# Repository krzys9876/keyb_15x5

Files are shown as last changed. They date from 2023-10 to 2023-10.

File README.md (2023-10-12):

# Diy mechanical keyboard

This is a dump of all the files that I used to build my custom mech keyboard.

## Layout

To prepare the base layout I used [keyboard-layout-editor](http://www.keyboard-layout-editor.com/). 

I ended-up with [15x5 layout with split space](https://gist.github.com/krzys9876/6718b1eb58f1728975fdd1076bed487b). 
This was my key requirement since what I really wanted was a keyboard with mouse functions built-in. Now, using arrows as mouse movements and split keyboard as left-mid-right mouse buttons I do not need mouse at all. 
Well, maybe this is not the most usefull and ergonomic way to handle mouse but hey, this is all for fun, right?

I tweaked the layout several times since than. The only constraint is the location of the 4 2u keys: space(s) and Enter.

keyb_15x5

## PCB

I created a PCB and schematic sketch using excellent [klepcbgen tool](https://github.com/jeroen94704/klepcbgen). This was a good starting point to tweak the design to match my ideas. 
I had some experience in designing PCBs and electonic circuits in general (see my [ZX Spectrum Diy project](https://github.com/krzys9876/ZX_Spectrum_diy) so it was quite easy. 

But all in all it was not that great - I totally failed with LEDs since I did not use proper footprint for WS2812B-2020 leds. So after I got the boards from JLCPBC it turned out that I cannot use LEDs at all. 
What you see now is a revised version that I did not (yet) put into production.

Other than that the board worked perfectly.

## Firmware

This is a fun project so I would not use any ready-to-use firmware. Anyway I don't think that any of available firmwares would allow me to use mouse. 
So I wrote my own simple version of keyboard handler using Arduino Micro templates and examples. The firmware uses [HID-project](https://github.com/NicoHood/HID).

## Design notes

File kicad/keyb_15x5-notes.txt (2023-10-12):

1. wydłużyć pady przy porcie USB
2. powiększyć pady dla LED
3. wydłużyć pady dla Atmega32u4
4. dodać silkscreen
5. pokazać orientację LED, diod i IC
6. opisać piny ICSP i AUX

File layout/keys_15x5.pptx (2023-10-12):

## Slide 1

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
Bksp

Caps

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
Enter

\

Home

End

Ins

Shift

Fn

Ctrl

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
Ctrl

Shift

PgUp

PgDn

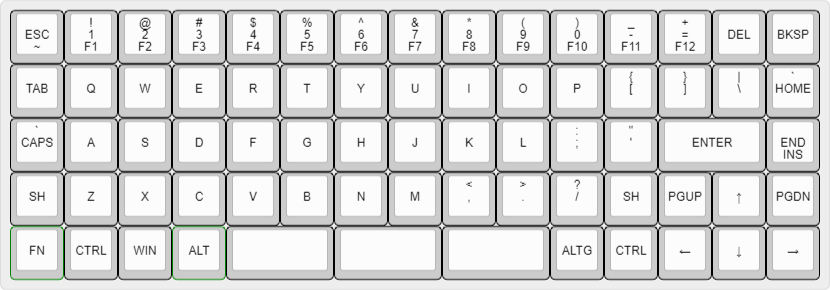
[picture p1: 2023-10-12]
layout/keyb_15x5.png

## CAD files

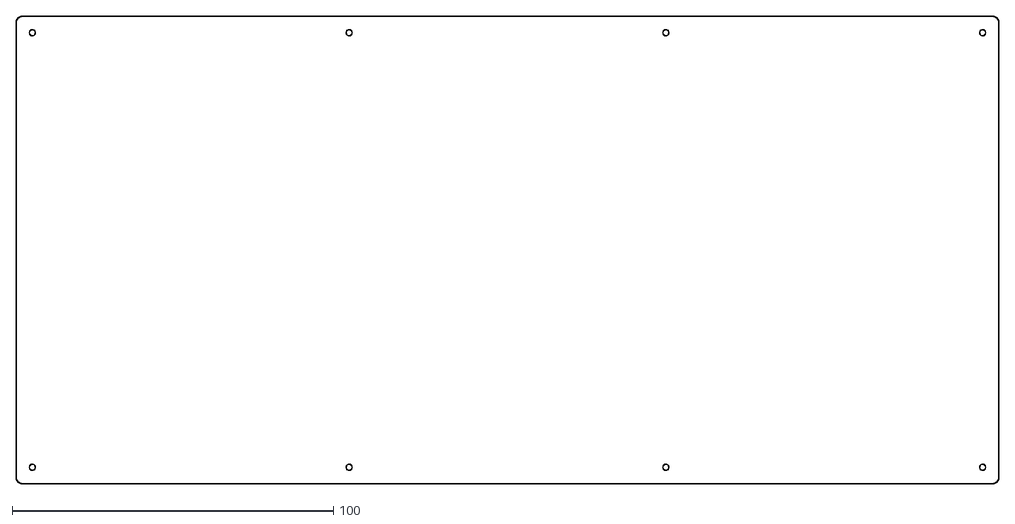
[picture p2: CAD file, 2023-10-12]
layout/e2b42e869952bdb01288ea0626760960afac74d6_bottom.dxf
305.9 x 145.4

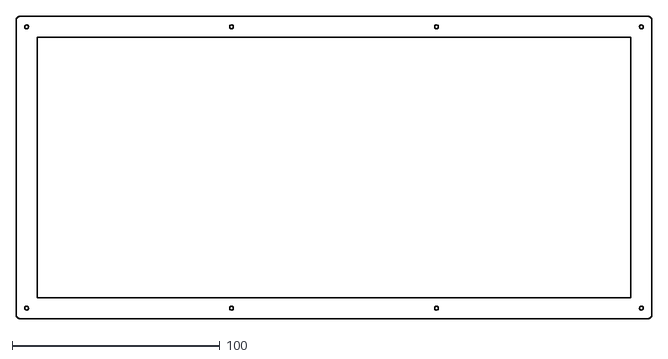
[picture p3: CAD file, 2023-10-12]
layout/e2b42e869952bdb01288ea0626760960afac74d6_closed.dxf
305.9 x 145.4

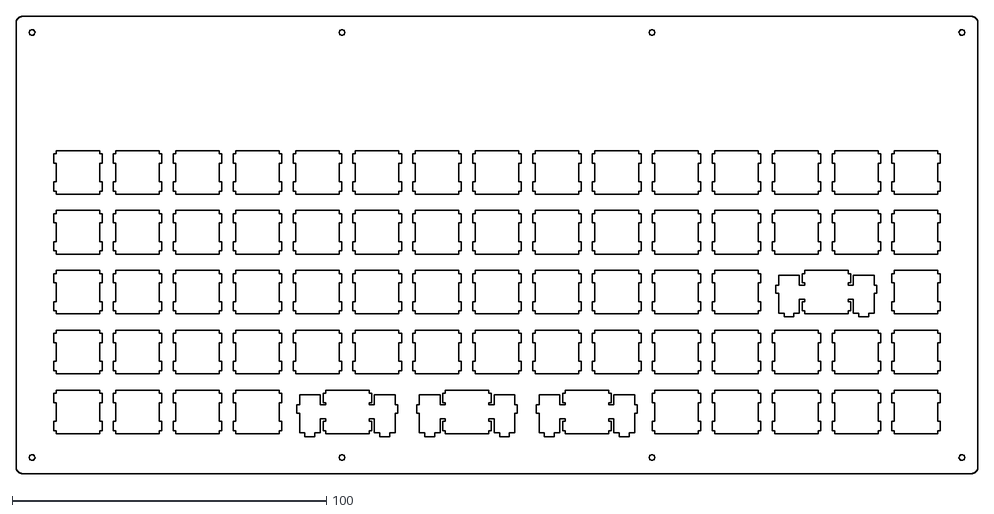
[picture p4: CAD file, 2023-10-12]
layout/e2b42e869952bdb01288ea0626760960afac74d6_switch.dxf
305.9 x 145.4

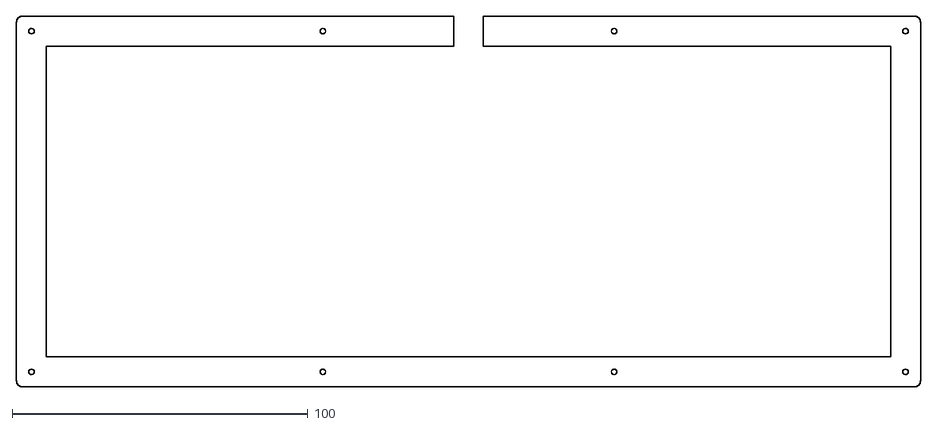
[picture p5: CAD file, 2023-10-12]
layout/71a48d4e9e6aa89030e797956ad6ba44319560fd_open.dxf
305.9 x 125.4

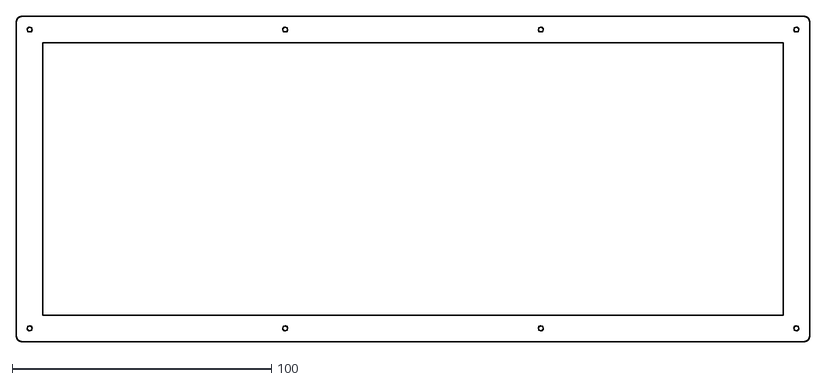
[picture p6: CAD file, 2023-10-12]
layout/71a48d4e9e6aa89030e797956ad6ba44319560fd_closed.dxf
305.9 x 125.4

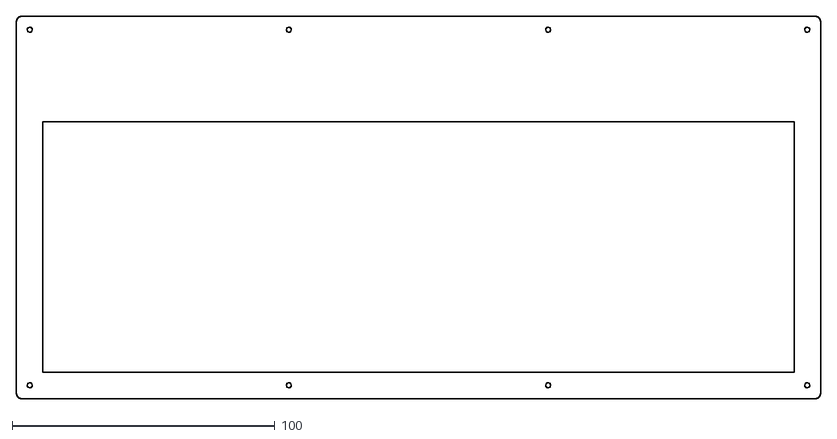
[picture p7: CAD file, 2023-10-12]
layout/e2b42e869952bdb01288ea0626760960afac74d6_top.dxf
305.9 x 145.4

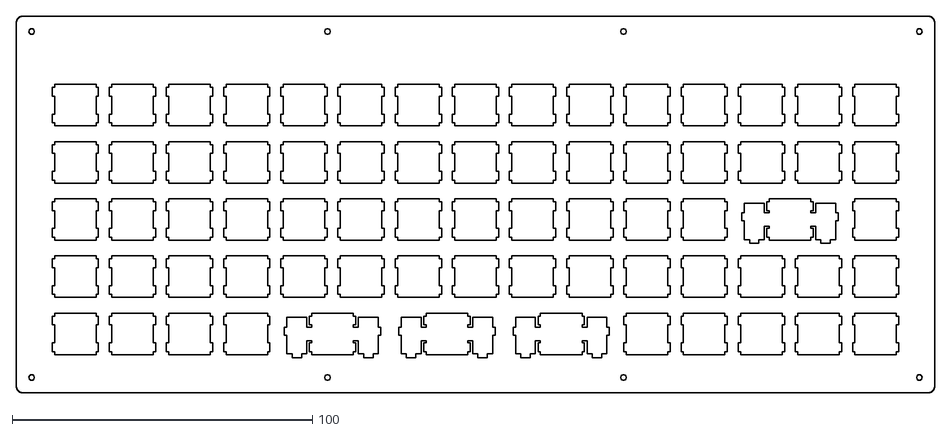
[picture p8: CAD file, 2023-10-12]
layout/71a48d4e9e6aa89030e797956ad6ba44319560fd_switch.dxf
305.9 x 125.4

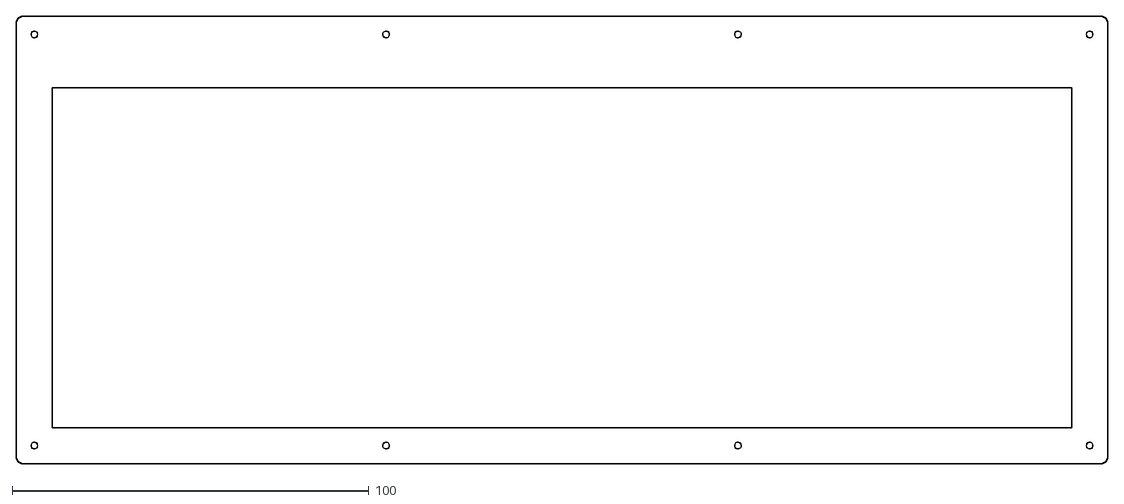
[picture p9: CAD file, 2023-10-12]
layout/71a48d4e9e6aa89030e797956ad6ba44319560fd_top.dxf
305.9 x 125.4

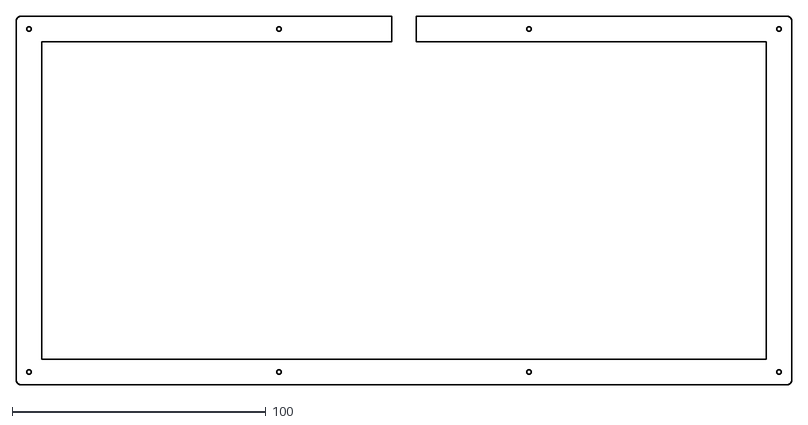
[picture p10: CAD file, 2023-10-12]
layout/e2b42e869952bdb01288ea0626760960afac74d6_open.dxf
305.9 x 145.4

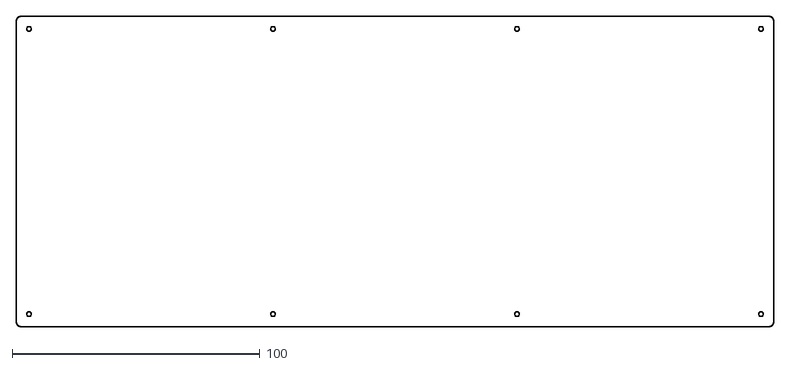
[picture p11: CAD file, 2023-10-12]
layout/71a48d4e9e6aa89030e797956ad6ba44319560fd_bottom.dxf
305.9 x 125.4

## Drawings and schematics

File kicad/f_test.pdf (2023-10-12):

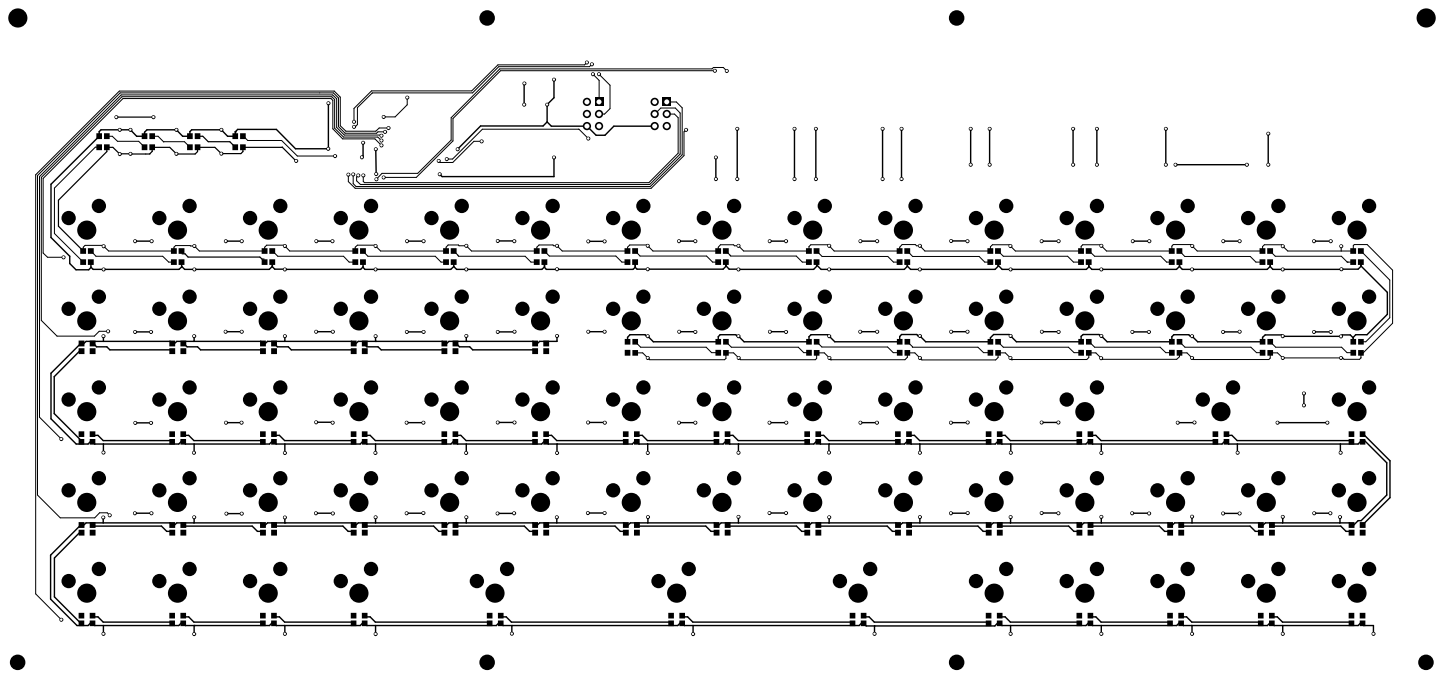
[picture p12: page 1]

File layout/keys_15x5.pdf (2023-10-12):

Esc | ! 1 F1 | @ 2 F2 | # F3 3 | $ F4 4 | % F5 5 | ^ F6 6 | & F7 7 | * F8 8 | ( F9 9 | ) F10 0 | _ F11 - | + F12 = | Del | Bksp
~` Tab | Q | W | E | R | T | Y | U | I | O | P | { [ | } ] | | \ | Home

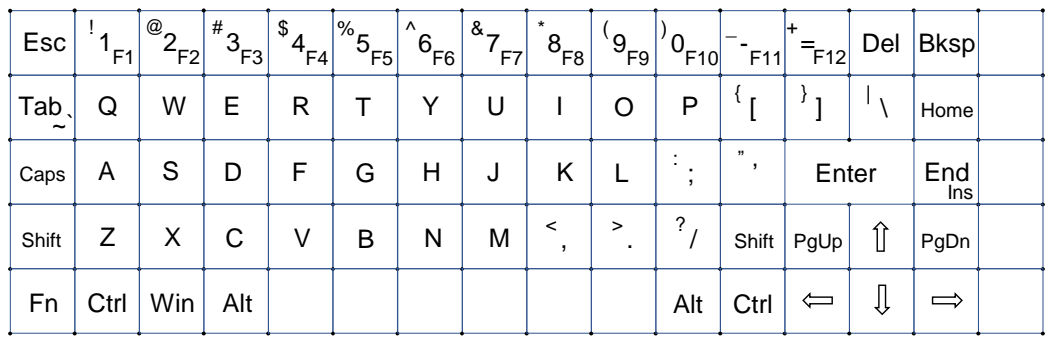
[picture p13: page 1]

Caps | A | S | D | F | G | H | J | K | L | : ; | ” ’ | Enter | | End Ins

Shift | Z | X | C | V | B | N | M | < , | > . | ? / | Shift | PgUp | | PgDn

Fn | Ctrl | Win | Alt | | | | | | | Alt | Ctrl

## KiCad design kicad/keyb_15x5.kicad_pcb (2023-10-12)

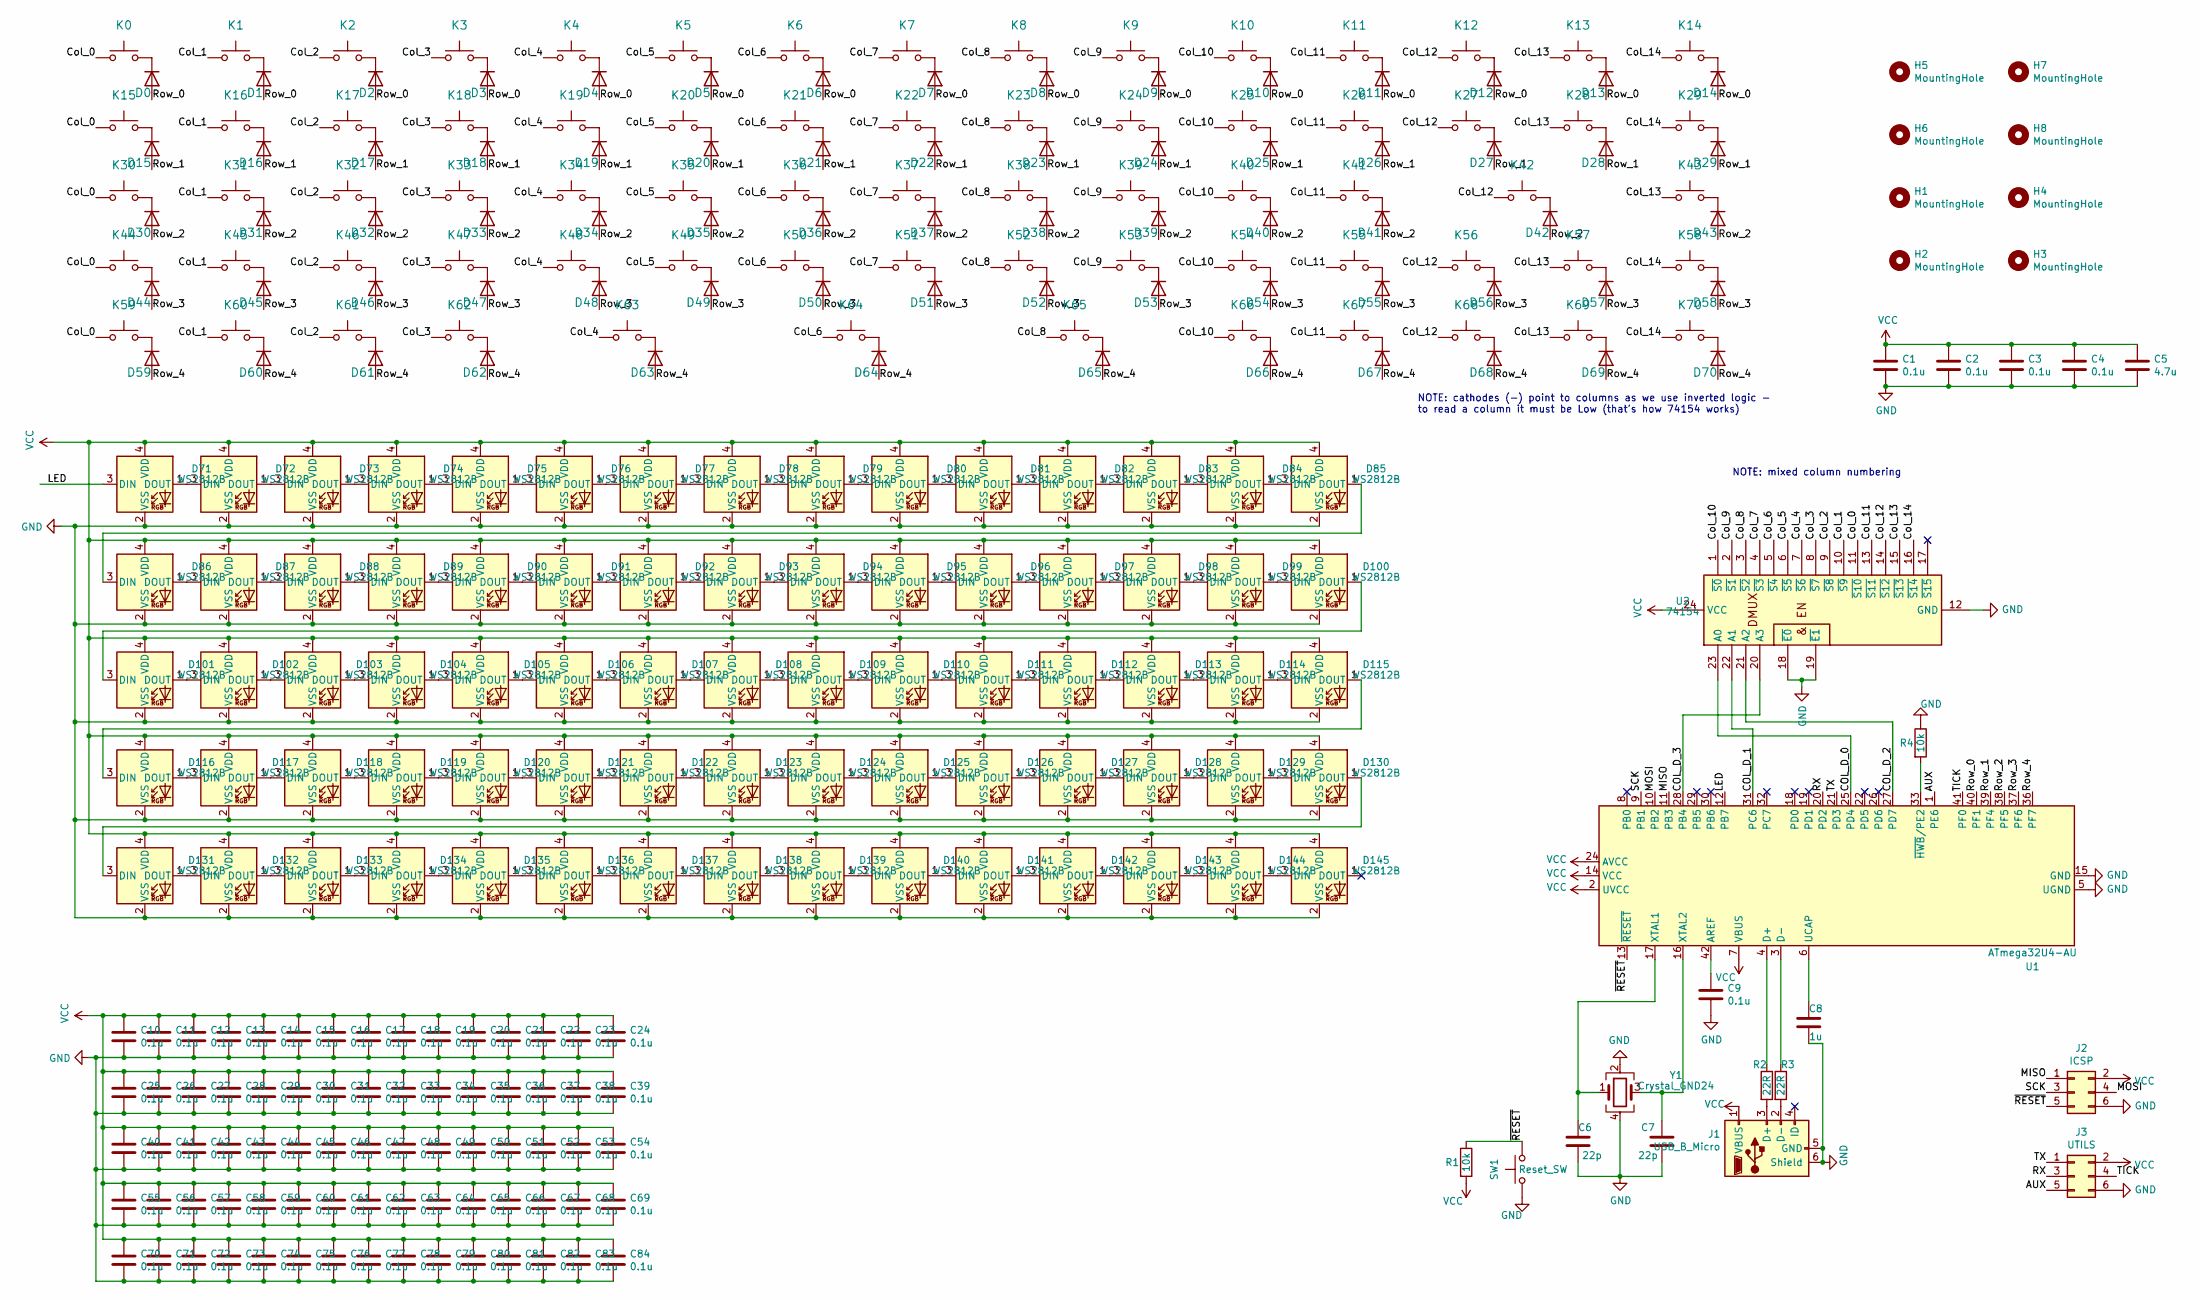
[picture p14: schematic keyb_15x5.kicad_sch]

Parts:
C1, C2, C3, C4, C9, C10, C11, C12, C13, C14, C15, C16, C17, C18, C19, C20, C21, C22, C23, C24, C25, C26, C27, C28, C29, C30, C31, C32, C33, C34, C35, C36, C37, C38, C39, C40, C41, C42, C43, C44, C45, C46, C47, C48, C49, C50, C51, C52, C53, C54, C55, C56, C57, C58, C59, C60, C61, C62, C63, C64, C65, C66, C67, C68, C69, C70, C71, C72, C73, C74, C75, C76, C77, C78, C79, C80, C81, C82, C83, C84: 0.1u; C_0805_2012Metric
C5: 4.7u; C_0805_2012Metric
C6, C7: 22p; C_0805_2012Metric
C8: 1u; C_0805_2012Metric
D0, D1, D2, D3, D4, D5, D6, D7, D8, D9, D10, D11, D12, D13, D14, D15, D16, D17, D18, D19, D20, D21, D22, D23, D24, D25, D26, D27, D28, D29, D30, D31, D32, D33, D34, D35, D36, D37, D38, D39, D40, D41, D42, D43, D44, D45, D46, D47, D48, D49, D50, D51, D52, D53, D54, D55, D56, D57, D58, D59, D60, D61, D62, D63, D64, D65, D66, D67, D68, D69, D70: D; D_0805_2012Metric_Pad1.15x1.40mm_HandSolder
D71, D72, D73, D74, D75, D76, D77, D78, D79, D80, D81, D82, D83, D84, D85, D86, D87, D88, D89, D90, D91, D92, D93, D94, D95, D96, D97, D98, D99, D100, D101, D102, D103, D104, D105, D106, D107, D108, D109, D110, D111, D112, D113, D114, D115, D116, D117, D118, D119, D120, D121, D122, D123, D124, D125, D126, D127, D128, D129, D130, D131, D132, D133, D134, D135, D136, D137, D138, D139, D140, D141, D142, D143, D144, D145: WS2812B; LED_WS2812B_PLCC4_5.0x5.0mm_P3.2mm
H1, H2, H3, H4, H5, H6, H7, H8: MountingHole; MountingHole_3.2mm_M3_DIN965
J1: USB_B_Micro; USB_Micro-B_Amphenol_10104110_Horizontal
J2: ICSP; PinHeader_2x03_P2.54mm_Vertical
J3: UTILS; PinHeader_2x03_P2.54mm_Vertical
K0, K1, K2, K3, K4, K5, K6, K7, K8, K9, K10, K11, K12, K13, K14, K15, K16, K17, K18, K19, K20, K21, K22, K23, K24, K25, K26, K27, K28, K29, K30, K31, K32, K33, K34, K35, K36, K37, K38, K39, K40, K41, K42, K43, K44, K45, K46, K47, K48, K49, K50, K51, K52, K53, K54, K55, K56, K57, K58, K59, K60, K61, K62, K63, K64, K65, K66, K67, K68, K69, K70: KEYSW; Kailh_socket_MX_platemount
R1, R4: 10k; R_0805_2012Metric_Pad1.15x1.40mm_HandSolder
R2, R3: 22R; R_0805_2012Metric_Pad1.15x1.40mm_HandSolder
SW1: Reset_SW; SW_Push_1P1T_NO_6x6mm_H9.5mm
U1: ATmega32U4-AU; TQFP-44_10x10mm_P0.8mm
U2: 74154; SOIC-24W_7.5x15.4mm_P1.27mm
Y1: Crystal_GND24; Crystal_SMD_3225-4Pin_3.2x2.5mm_HandSoldering

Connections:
/AUX: J3.5, U1.1 (PE6)
/COL_D_0: U1.25 (PD4), U2.23 (A0)
/COL_D_1: U1.31 (PC6), U2.22 (A1)
/COL_D_2: U1.27 (PD7), U2.21 (A2)
/COL_D_3: U1.28 (PB4), U2.20 (A3)
/Col_0: K0.1, K15.1, K30.1, K44.1, K59.1, U2.11 (~S10)
/Col_1: K1.1, K16.1, K31.1, K45.1, K60.1, U2.10 (~S9)
/Col_2: K2.1, K17.1, K32.1, K46.1, K61.1, U2.9 (~S8)
/Col_3: K3.1, K18.1, K33.1, K47.1, K62.1, U2.8 (~S7)
/Col_4: K4.1, K19.1, K34.1, K48.1, K63.1, U2.7 (~S6)
/Col_5: K5.1, K20.1, K35.1, K49.1, U2.6 (~S5)
/Col_6: K6.1, K21.1, K36.1, K50.1, K64.1, U2.5 (~S4)
/Col_7: K7.1, K22.1, K37.1, K51.1, U2.4 (~S3)
/Col_8: K8.1, K23.1, K38.1, K52.1, K65.1, U2.3 (~S2)
/Col_9: K9.1, K24.1, K39.1, K53.1, U2.2 (~S1)
/Col_10: K10.1, K25.1, K40.1, K54.1, K66.1, U2.1 (~S0)
/Col_11: K11.1, K26.1, K41.1, K55.1, K67.1, U2.13 (~S11)
/Col_12: K12.1, K27.1, K42.1, K56.1, K68.1, U2.14 (~S12)
/Col_13: K13.1, K28.1, K43.1, K57.1, K69.1, U2.15 (~S13)
/Col_14: K14.1, K29.1, K58.1, K70.1, U2.16 (~S14)
/LED: D71.3 (DIN), U1.12 (PB7)
/MISO: J2.1, U1.11 (PB3)
/MOSI: J2.4, U1.10 (PB2)
/RX: J3.3, U1.20 (PD2)
/Row_0: D0.2 (A), D1.2 (A), D2.2 (A), D3.2 (A), D4.2 (A), D5.2 (A), D6.2 (A), D7.2 (A), D8.2 (A), D9.2 (A), D10.2 (A), D11.2 (A), D12.2 (A), D13.2 (A), D14.2 (A), U1.40 (PF1)
/Row_1: D15.2 (A), D16.2 (A), D17.2 (A), D18.2 (A), D19.2 (A), D20.2 (A), D21.2 (A), D22.2 (A), D23.2 (A), D24.2 (A), D25.2 (A), D26.2 (A), D27.2 (A), D28.2 (A), D29.2 (A), U1.39 (PF4)
/Row_2: D30.2 (A), D31.2 (A), D32.2 (A), D33.2 (A), D34.2 (A), D35.2 (A), D36.2 (A), D37.2 (A), D38.2 (A), D39.2 (A), D40.2 (A), D41.2 (A), D42.2 (A), D43.2 (A), U1.38 (PF5)
/Row_3: D44.2 (A), D45.2 (A), D46.2 (A), D47.2 (A), D48.2 (A), D49.2 (A), D50.2 (A), D51.2 (A), D52.2 (A), D53.2 (A), D54.2 (A), D55.2 (A), D56.2 (A), D57.2 (A), D58.2 (A), U1.37 (PF6)
/Row_4: D59.2 (A), D60.2 (A), D61.2 (A), D62.2 (A), D63.2 (A), D64.2 (A), D65.2 (A), D66.2 (A), D67.2 (A), D68.2 (A), D69.2 (A), D70.2 (A), U1.36 (PF7)
/SCK: J2.3, U1.9 (PB1)
/TICK: J3.4, U1.41 (PF0)
/TX: J3.1, U1.21 (PD3)
/~RESET: J2.5, R1.1, SW1.2, U1.13 (~RESET)
GND: C1.2, C2.2, C3.2, C4.2, C5.2, C6.2, C7.2, C8.2, C9.2, C10.2, C11.2, C12.2, C13.2, C14.2, C15.2, C16.2, C17.2, C18.2, C19.2, C20.2, C21.2, C22.2, C23.2, C24.2, C25.2, C26.2, C27.2, C28.2, C29.2, C30.2, C31.2, C32.2, C33.2, C34.2, C35.2, C36.2, C37.2, C38.2, C39.2, C40.2, C41.2, C42.2, C43.2, C44.2, C45.2, C46.2, C47.2, C48.2, C49.2, C50.2, C51.2, C52.2, C53.2, C54.2, C55.2, C56.2, C57.2, C58.2, C59.2, C60.2, C61.2, C62.2, C63.2, C64.2, C65.2, C66.2, C67.2, C68.2, C69.2, C70.2, C71.2, C72.2, C73.2, C74.2, C75.2, C76.2, C77.2, C78.2, C79.2, C80.2, C81.2, C82.2, C83.2, C84.2, D71.2 (VSS), D72.2 (VSS), D73.2 (VSS), D74.2 (VSS), D75.2 (VSS), D76.2 (VSS), D77.2 (VSS), D78.2 (VSS), D79.2 (VSS), D80.2 (VSS), D81.2 (VSS), D82.2 (VSS), D83.2 (VSS), D84.2 (VSS), D85.2 (VSS), D86.2 (VSS), D87.2 (VSS), D88.2 (VSS), D89.2 (VSS), D90.2 (VSS), D91.2 (VSS), D92.2 (VSS), D93.2 (VSS), D94.2 (VSS), D95.2 (VSS), D96.2 (VSS), D97.2 (VSS), D98.2 (VSS), D99.2 (VSS), D100.2 (VSS), D101.2 (VSS), D102.2 (VSS), D103.2 (VSS), D104.2 (VSS), D105.2 (VSS), D106.2 (VSS), D107.2 (VSS), D108.2 (VSS), D109.2 (VSS), D110.2 (VSS), D111.2 (VSS), D112.2 (VSS), D113.2 (VSS), D114.2 (VSS), D115.2 (VSS), D116.2 (VSS), D117.2 (VSS), D118.2 (VSS), D119.2 (VSS), D120.2 (VSS), D121.2 (VSS), D122.2 (VSS), D123.2 (VSS), D124.2 (VSS), D125.2 (VSS), D126.2 (VSS), D127.2 (VSS), D128.2 (VSS), D129.2 (VSS), D130.2 (VSS), D131.2 (VSS), D132.2 (VSS), D133.2 (VSS), D134.2 (VSS), D135.2 (VSS), D136.2 (VSS), D137.2 (VSS), D138.2 (VSS), D139.2 (VSS), D140.2 (VSS), D141.2 (VSS), D142.2 (VSS), D143.2 (VSS), D144.2 (VSS), D145.2 (VSS), J1.5 (GND), J1.6 (Shield), J2.6, J3.6, R4.1, SW1.1, U1.5 (UGND), U1.15 (GND), U1.23 (GND), U1.35 (GND), U1.43 (GND), U2.12 (GND), U2.18 (~E0), U2.19 (~E1), Y1.2, Y1.4
unnamed: D0.1 (K), K0.2
unnamed: D1.1 (K), K1.2
unnamed: D2.1 (K), K2.2
unnamed: D3.1 (K), K3.2
unnamed: D4.1 (K), K4.2
unnamed: D5.1 (K), K5.2
unnamed: D6.1 (K), K6.2
unnamed: D7.1 (K), K7.2
unnamed: D8.1 (K), K8.2
unnamed: D9.1 (K), K9.2
unnamed: D10.1 (K), K10.2
unnamed: D11.1 (K), K11.2
unnamed: D12.1 (K), K12.2
unnamed: D13.1 (K), K13.2
unnamed: D14.1 (K), K14.2
unnamed: D15.1 (K), K15.2
unnamed: D16.1 (K), K16.2
unnamed: D17.1 (K), K17.2
unnamed: D18.1 (K), K18.2
unnamed: D19.1 (K), K19.2
unnamed: D20.1 (K), K20.2
unnamed: D21.1 (K), K21.2
unnamed: D22.1 (K), K22.2
unnamed: D23.1 (K), K23.2
unnamed: D24.1 (K), K24.2
unnamed: D25.1 (K), K25.2
unnamed: D26.1 (K), K26.2
unnamed: D27.1 (K), K27.2
unnamed: D28.1 (K), K28.2
unnamed: D29.1 (K), K29.2
unnamed: D30.1 (K), K30.2
unnamed: D31.1 (K), K31.2
unnamed: D32.1 (K), K32.2
unnamed: D33.1 (K), K33.2
unnamed: D34.1 (K), K34.2
unnamed: D35.1 (K), K35.2
unnamed: D36.1 (K), K36.2
unnamed: D37.1 (K), K37.2
unnamed: D38.1 (K), K38.2
unnamed: D39.1 (K), K39.2
unnamed: D40.1 (K), K40.2
unnamed: D41.1 (K), K41.2
unnamed: D42.1 (K), K42.2
unnamed: D43.1 (K), K43.2
unnamed: D44.1 (K), K44.2
unnamed: D45.1 (K), K45.2
unnamed: D46.1 (K), K46.2
unnamed: D47.1 (K), K47.2
unnamed: D48.1 (K), K48.2
unnamed: D49.1 (K), K49.2
unnamed: D50.1 (K), K50.2
unnamed: D51.1 (K), K51.2
unnamed: D52.1 (K), K52.2
unnamed: D53.1 (K), K53.2
unnamed: D54.1 (K), K54.2
unnamed: D55.1 (K), K55.2
unnamed: D56.1 (K), K56.2
unnamed: D57.1 (K), K57.2
unnamed: D58.1 (K), K58.2
unnamed: D59.1 (K), K59.2
unnamed: D60.1 (K), K60.2
unnamed: D61.1 (K), K61.2
unnamed: D62.1 (K), K62.2
unnamed: D63.1 (K), K63.2
unnamed: D64.1 (K), K64.2
unnamed: D65.1 (K), K65.2
unnamed: D66.1 (K), K66.2
unnamed: D67.1 (K), K67.2
unnamed: D68.1 (K), K68.2
unnamed: D69.1 (K), K69.2
unnamed: D70.1 (K), K70.2
unnamed: D71.1 (DOUT), D72.3 (DIN)
unnamed: D72.1 (DOUT), D73.3 (DIN)
unnamed: D73.1 (DOUT), D74.3 (DIN)
unnamed: D74.1 (DOUT), D75.3 (DIN)
unnamed: D75.1 (DOUT), D76.3 (DIN)
unnamed: D76.1 (DOUT), D77.3 (DIN)
unnamed: D77.1 (DOUT), D78.3 (DIN)
unnamed: D78.1 (DOUT), D79.3 (DIN)
unnamed: D79.1 (DOUT), D80.3 (DIN)
unnamed: D80.1 (DOUT), D81.3 (DIN)
unnamed: D81.1 (DOUT), D82.3 (DIN)
unnamed: D82.1 (DOUT), D83.3 (DIN)
unnamed: D83.1 (DOUT), D84.3 (DIN)
unnamed: D84.1 (DOUT), D85.3 (DIN)
unnamed: D85.1 (DOUT), D86.3 (DIN)
unnamed: D86.1 (DOUT), D87.3 (DIN)
unnamed: D87.1 (DOUT), D88.3 (DIN)
unnamed: D88.1 (DOUT), D89.3 (DIN)
unnamed: D89.1 (DOUT), D90.3 (DIN)
unnamed: D90.1 (DOUT), D91.3 (DIN)
unnamed: D91.1 (DOUT), D92.3 (DIN)
unnamed: D92.1 (DOUT), D93.3 (DIN)
unnamed: D93.1 (DOUT), D94.3 (DIN)
unnamed: D94.1 (DOUT), D95.3 (DIN)
unnamed: D95.1 (DOUT), D96.3 (DIN)
unnamed: D96.1 (DOUT), D97.3 (DIN)
unnamed: D97.1 (DOUT), D98.3 (DIN)
unnamed: D98.1 (DOUT), D99.3 (DIN)
unnamed: D99.1 (DOUT), D100.3 (DIN)
unnamed: D100.1 (DOUT), D101.3 (DIN)
unnamed: D101.1 (DOUT), D102.3 (DIN)
unnamed: D102.1 (DOUT), D103.3 (DIN)
unnamed: D103.1 (DOUT), D104.3 (DIN)
unnamed: D104.1 (DOUT), D105.3 (DIN)
unnamed: D105.1 (DOUT), D106.3 (DIN)
unnamed: D106.1 (DOUT), D107.3 (DIN)
unnamed: D107.1 (DOUT), D108.3 (DIN)
unnamed: D108.1 (DOUT), D109.3 (DIN)
unnamed: D109.1 (DOUT), D110.3 (DIN)
unnamed: D110.1 (DOUT), D111.3 (DIN)
unnamed: D111.1 (DOUT), D112.3 (DIN)
unnamed: D112.1 (DOUT), D113.3 (DIN)
unnamed: D113.1 (DOUT), D114.3 (DIN)
unnamed: D114.1 (DOUT), D115.3 (DIN)
unnamed: D115.1 (DOUT), D116.3 (DIN)
unnamed: D116.1 (DOUT), D117.3 (DIN)
unnamed: D117.1 (DOUT), D118.3 (DIN)
unnamed: D118.1 (DOUT), D119.3 (DIN)
unnamed: D119.1 (DOUT), D120.3 (DIN)
unnamed: D120.1 (DOUT), D121.3 (DIN)
unnamed: D121.1 (DOUT), D122.3 (DIN)
unnamed: D122.1 (DOUT), D123.3 (DIN)
unnamed: D123.1 (DOUT), D124.3 (DIN)
unnamed: D124.1 (DOUT), D125.3 (DIN)
unnamed: D125.1 (DOUT), D126.3 (DIN)
unnamed: D126.1 (DOUT), D127.3 (DIN)
unnamed: D127.1 (DOUT), D128.3 (DIN)
unnamed: D128.1 (DOUT), D129.3 (DIN)
unnamed: D129.1 (DOUT), D130.3 (DIN)
unnamed: D130.1 (DOUT), D131.3 (DIN)
unnamed: D131.1 (DOUT), D132.3 (DIN)
unnamed: D132.1 (DOUT), D133.3 (DIN)
unnamed: D133.1 (DOUT), D134.3 (DIN)
unnamed: D134.1 (DOUT), D135.3 (DIN)
unnamed: D135.1 (DOUT), D136.3 (DIN)
unnamed: D136.1 (DOUT), D137.3 (DIN)
unnamed: D137.1 (DOUT), D138.3 (DIN)
unnamed: D138.1 (DOUT), D139.3 (DIN)
unnamed: D139.1 (DOUT), D140.3 (DIN)
unnamed: D140.1 (DOUT), D141.3 (DIN)
unnamed: D141.1 (DOUT), D142.3 (DIN)
unnamed: D142.1 (DOUT), D143.3 (DIN)
unnamed: D143.1 (DOUT), D144.3 (DIN)
unnamed: D144.1 (DOUT), D145.3 (DIN)
unnamed: J1.3 (D+), R2.2
unnamed: J1.2 (D-), R3.2
unnamed: C9.1, U1.42 (AREF)
unnamed: R2.1, U1.4 (D+)
unnamed: R3.1, U1.3 (D-)
unnamed: C8.1, U1.6 (UCAP)
unnamed: C6.1, U1.17 (XTAL1), Y1.1
unnamed: C7.1, U1.16 (XTAL2), Y1.3
unnamed: R4.2, U1.33 (~HWB/PE2)
VCC: C1.1, C2.1, C3.1, C4.1, C5.1, C10.1, C11.1, C12.1, C13.1, C14.1, C15.1, C16.1, C17.1, C18.1, C19.1, C20.1, C21.1, C22.1, C23.1, C24.1, C25.1, C26.1, C27.1, C28.1, C29.1, C30.1, C31.1, C32.1, C33.1, C34.1, C35.1, C36.1, C37.1, C38.1, C39.1, C40.1, C41.1, C42.1, C43.1, C44.1, C45.1, C46.1, C47.1, C48.1, C49.1, C50.1, C51.1, C52.1, C53.1, C54.1, C55.1, C56.1, C57.1, C58.1, C59.1, C60.1, C61.1, C62.1, C63.1, C64.1, C65.1, C66.1, C67.1, C68.1, C69.1, C70.1, C71.1, C72.1, C73.1, C74.1, C75.1, C76.1, C77.1, C78.1, C79.1, C80.1, C81.1, C82.1, C83.1, C84.1, D71.4 (VDD), D72.4 (VDD), D73.4 (VDD), D74.4 (VDD), D75.4 (VDD), D76.4 (VDD), D77.4 (VDD), D78.4 (VDD), D79.4 (VDD), D80.4 (VDD), D81.4 (VDD), D82.4 (VDD), D83.4 (VDD), D84.4 (VDD), D85.4 (VDD), D86.4 (VDD), D87.4 (VDD), D88.4 (VDD), D89.4 (VDD), D90.4 (VDD), D91.4 (VDD), D92.4 (VDD), D93.4 (VDD), D94.4 (VDD), D95.4 (VDD), D96.4 (VDD), D97.4 (VDD), D98.4 (VDD), D99.4 (VDD), D100.4 (VDD), D101.4 (VDD), D102.4 (VDD), D103.4 (VDD), D104.4 (VDD), D105.4 (VDD), D106.4 (VDD), D107.4 (VDD), D108.4 (VDD), D109.4 (VDD), D110.4 (VDD), D111.4 (VDD), D112.4 (VDD), D113.4 (VDD), D114.4 (VDD), D115.4 (VDD), D116.4 (VDD), D117.4 (VDD), D118.4 (VDD), D119.4 (VDD), D120.4 (VDD), D121.4 (VDD), D122.4 (VDD), D123.4 (VDD), D124.4 (VDD), D125.4 (VDD), D126.4 (VDD), D127.4 (VDD), D128.4 (VDD), D129.4 (VDD), D130.4 (VDD), D131.4 (VDD), D132.4 (VDD), D133.4 (VDD), D134.4 (VDD), D135.4 (VDD), D136.4 (VDD), D137.4 (VDD), D138.4 (VDD), D139.4 (VDD), D140.4 (VDD), D141.4 (VDD), D142.4 (VDD), D143.4 (VDD), D144.4 (VDD), D145.4 (VDD), J1.1 (VBUS), J2.2, J3.2, R1.2, U1.2 (UVCC), U1.7 (VBUS), U1.14 (VCC), U1.24 (AVCC), U1.34 (VCC), U1.44 (AVCC), U2.24 (VCC)

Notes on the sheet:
NOTE: mixed column numbering
NOTE: cathodes (-) point to columns as we use inverted logic - to read a column it must be Low (that's how 74154 works)

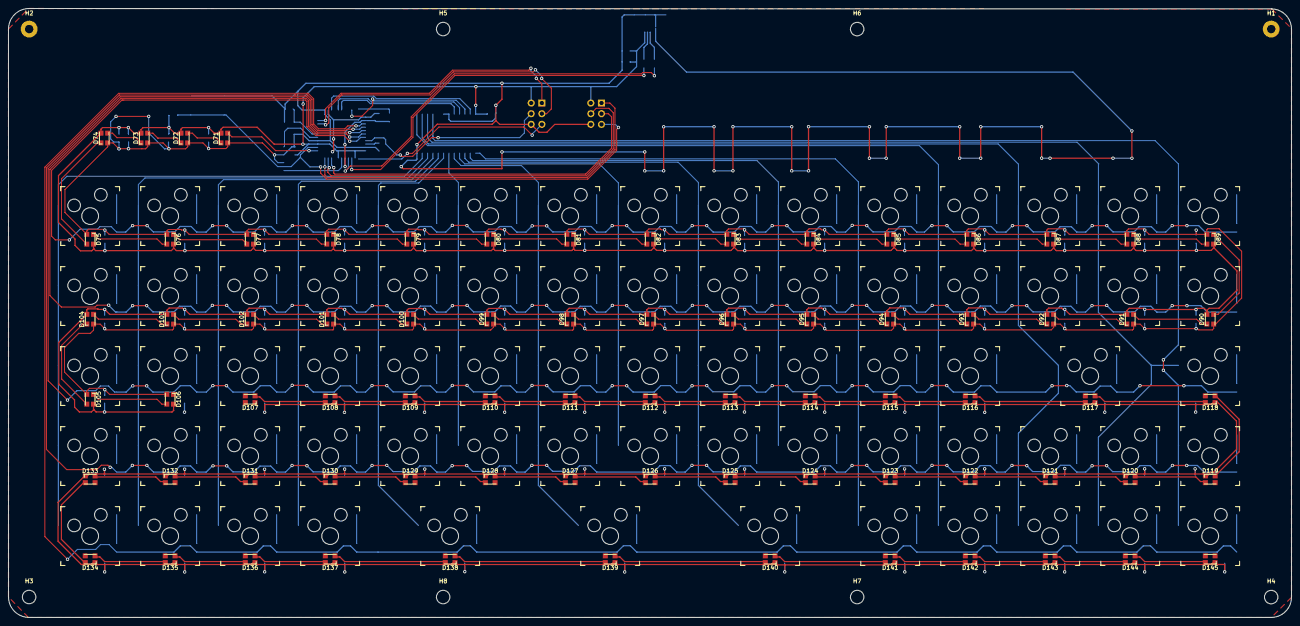
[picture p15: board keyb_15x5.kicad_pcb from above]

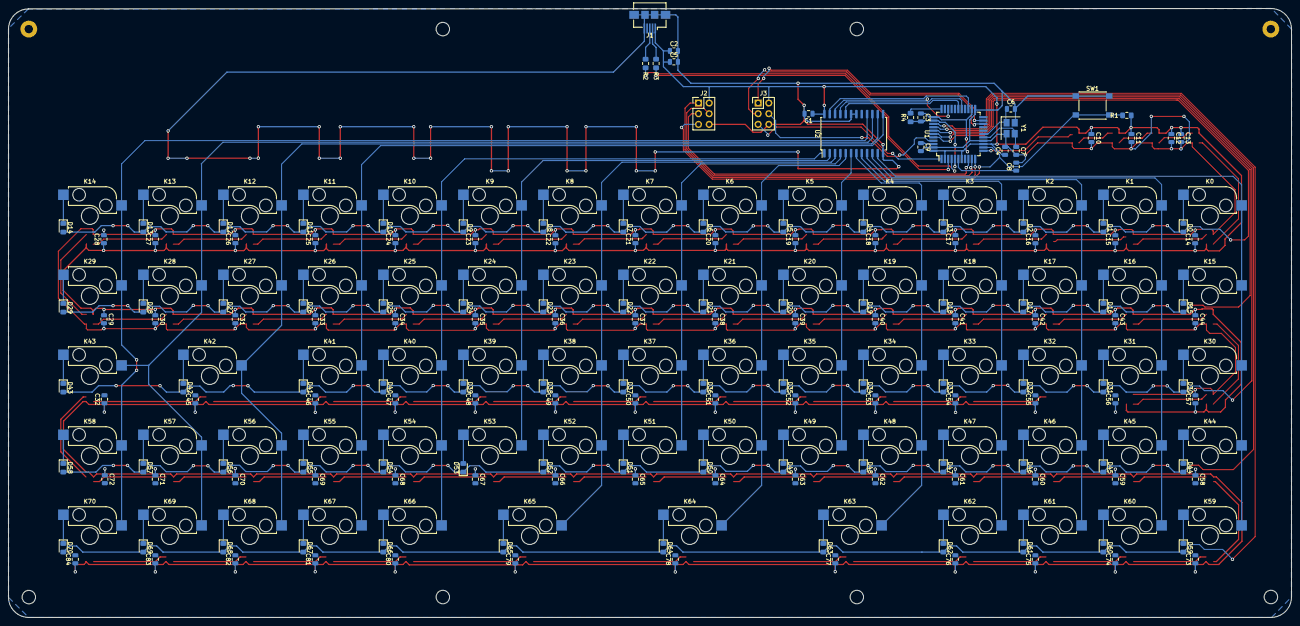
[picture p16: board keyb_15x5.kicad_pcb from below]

Board: 2 copper layers, 305.5 x 145.0 mm, 320 parts (166 on the bottom side), 189 nets.

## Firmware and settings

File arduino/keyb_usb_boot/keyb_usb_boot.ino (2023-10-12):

#include "HID-Project.h"
#include "KeyDebouncer.h"
#include "ArrList.h"
#include "KeyboardMap.h"
#include <Wire.h>
#include <Adafruit_NeoPixel.h>

#define MIN_BETWEEN_MILLIS 10
#define RELEASE_MILLIS 10
#define TICK_PIN 23
#define LED_TICKS 10

KeyConfig config = {0,false,false}; // 0 - standard, 1 - F-keys

#define NUMPIXELS 8
#define LED_PIN 11
Adafruit_NeoPixel pixels(NUMPIXELS, LED_PIN, NEO_GRB + NEO_KHZ800);

KeyDebouncer keyDebouncer[SIZE];

ArrList<KeyPos> keyb=ArrList<KeyPos>(SIZE);
ArrList<KeyPos> keybPrev=ArrList<KeyPos>(SIZE);

void setup() {
  BootKeyboard.begin();
  BootMouse.begin();
  Serial.begin(115200);
  //Serial1.begin(115200);
  pixels.begin(); 
  Wire.begin();

  for(uint8_t i=0;i<COL_PINS;i++) pinMode(COLpins[i], OUTPUT); 
  for(uint8_t i=0;i<ROWS;i++) pinMode(ROWpins[i], INPUT_PULLUP);   
  pinMode(TICK_PIN,OUTPUT);
}

void loop() {
  static long counter=0;
  static bool loopTick=true;

  readMatrix();
  bool pr=false;
  long kMillis=millis();
  pr|=processPress(kMillis); 
  pr|=processRelease(kMillis);
  clearIfEmpty(kMillis);  

  if(pr) {    
    copyKeyState(); 
    /*Serial1.println("no of pressed keys "+String(keyb.getSize()));
    uint32_t c=pixels.Color(20,20,20);
    uint32_t blank=pixels.Color(0,0,0);
    for(int i=0;i<keyb.getSize();i++) pixels.setPixelColor(i,c);
    for(int i=keyb.getSize();i<SIZE;i++) pixels.setPixelColor(i,blank);*/
  }

  // show pixels every X ticks - it does not make sense to do it every time
  //if((counter % LED_TICKS) == 0) pixels.show();  
  counter++;
  loopTick=!loopTick;
  digitalWrite(TICK_PIN,loopTick);  
}

void readMatrix() {
  keyb.empty();
  for(uint8_t c=0;c<COLS;c++) {
    writeColumns(c);
    for(uint8_t r=0;r<ROWS;r++) {
      uint8_t k=digitalRead(ROWpins[r]);
      if(k==LOW) {
        //BootKeyboard.write('A');
        //delay(100);
        keyb.insertVal({r,c});
      }
    }
  }
}

KeyRaw functionOverride(KeyPos pos) {
  KeyRaw ret = pos.code(config.layer);
  if(config.mouse) {
    switch(ret.key) {
      case KEY_UP_ARROW : ret.function = FN_MOUSE_UP; break;
      case KEY_DOWN_ARROW : ret.function = FN_MOUSE_DOWN; break;
      case KEY_LEFT_ARROW : ret.function = FN_MOUSE_LEFT; break;
      case KEY_RIGHT_ARROW : ret.function = FN_MOUSE_RIGHT; break;
    }
    if(pos.isLeftSpace()) ret.function = FN_MOUSE_BTN_LEFT;
    else if(pos.isRightSpace()) ret.function = FN_MOUSE_BTN_RIGHT;
  }
  if(pos.isFn()) ret.function = FN_SWITCH;
  else if(pos.isMouse()) ret.function = FN_MOUSE;
  else if(pos.isWheel()) ret.function = FN_MOUSE_WHEEL;

  return ret;
}

bool pressFunction(KeyPos pos) {
  bool pressed=false;
  KeyRaw code = functionOverride(pos);
  //Serial.println("pressed Function "+String(pos.row)+" "+String(pos.col)+" "+String(COLmap[pos.col])+" "+String(pos.isLeftSpace())+" "+String(pos.isRightSpace())+" "+String(code.function));
  if(code.isFunction() && !keyDebouncer[pos.index()].isPressConfirmed()) {
    switch(code.function) {
      case FN_SWITCH : config.layer=1; break;
      case FN_MOUSE : config.mouse=true; break;
      case FN_MOUSE_BTN_LEFT : BootMouse.press(MOUSE_LEFT); break;
      case FN_MOUSE_BTN_RIGHT : BootMouse.press(MOUSE_RIGHT); break;
      case FN_MOUSE_WHEEL : config.wheel=true; break;
      case FN_MOUSE_UP : if(config.wheel) BootMouse.move(0,0,1); else BootMouse.move(0,-1,0); break;
      case FN_MOUSE_DOWN : if(config.wheel) BootMouse.move(0,0,-1); else BootMouse.move(0,1,0); break;
      case FN_MOUSE_LEFT : BootMouse.move(-1,0,0); break;
      case FN_MOUSE_RIGHT : BootMouse.move(1,0,0); break;
      default : break;
    }
    keyDebouncer[pos.index()].confirmPress();
    pressed=true;
  }
  return pressed;
}

KeyboardKeycode keycodeOverride(KeyPos pos) {  
  KeyboardKeycode actualCode=pos.code(config.layer).key;
  if(config.mouse) {
    switch(actualCode) {
      // Ignore arrows when mouse is active
      case KEY_DOWN_ARROW : actualCode=KEY_RESERVED; break;
      case KEY_UP_ARROW : actualCode=KEY_RESERVED; break;
      case KEY_LEFT_ARROW : actualCode=KEY_RESERVED; break;
      case KEY_RIGHT_ARROW : actualCode=KEY_RESERVED; break;
      default : break;
    }
    if(pos.isLeftSpace() || pos.isRightSpace()) actualCode = KEY_RESERVED;
  } else {
    switch(actualCode) {
      case KEY_DOWN_ARROW : if(config.wheel) actualCode=KEY_PAGE_DOWN; break;
      case KEY_UP_ARROW : if(config.wheel) actualCode=KEY_PAGE_UP; break;
      default : break;
    }
  }
  return actualCode;
}

bool pressNormal(KeyPos pos) {
  bool pressed=false;
  if(pos.code(config.layer).isStandard()) {
    //Serial.println(String(index)+" - "+String(functionIndex));
    //if(index==functionIndex) Serial.println(String(keyDebouncer[index].isPressed()));
    KeyRaw code=pos.code(config.layer);
    if(code.mod!=KEY_RESERVED) BootKeyboard.add(code.mod);
    KeyboardKeycode actualCode=keycodeOverride(pos);
    if(actualCode!=KEY_RESERVED) BootKeyboard.add(actualCode);
    pressed=code.standardNonEmpty();
    //Serial.println("pressed " + String(code.key) + " (" + String(code.mod)+")");        
  }
  return pressed;
}

bool processPressOne(uint8_t keyIndex, long kMillis, bool (*process)(KeyPos pos)) {
  bool pressed=false;
  KeyPos pos=keyb.getVal(keyIndex);
  if(keybPrev.notExists(pos) && keyDebouncer[pos.index()].shouldPress(kMillis)) pressed|=(*process)(pos);
  return pressed;
}

bool processPressList(long kMillis, bool (*process)(KeyPos pos)) {
  bool pressed = false;
  for(uint8_t i=0;i<keyb.getSize();i++) pressed|=processPressOne(i,kMillis,process);
  return pressed;
}

uint8_t calcMouseMove(long kMillis, long mouseMoveStartMills, bool slow) {
  static long lastMillis=0;
  if(lastMillis<mouseMoveStartMills) lastMillis=mouseMoveStartMills;
  long move=0;  
  float speed=mouseSpeedRatio(kMillis-mouseMoveStartMills,slow);
  if(kMillis>lastMillis) move=speed*(kMillis-lastMillis);
  if(speed==0 || move>0) lastMillis=kMillis;
  //Serial.println("lastMillis="+String(lastMillis)+"millis="+String(kMillis)+" start="+String(mouseMoveStartMills)+" speed="+String(speed)+" move="+String(move));
  uint8_t moveRet;
  if(move<127) moveRet=move; else moveRet=0;
  return moveRet;
}

void keepMouseMoving(KeyRaw code, uint8_t move) {
  switch(code.function) {
    case FN_MOUSE_UP : if(config.wheel) BootMouse.move(0,0,move); else BootMouse.move(0,-move,0); break;
    case FN_MOUSE_DOWN : if(config.wheel) BootMouse.move(0,0,-move); else BootMouse.move(0,move,0); break;
    case FN_MOUSE_LEFT : BootMouse.move(-move,0,0); break;
    case FN_MOUSE_RIGHT : BootMouse.move(move,0,0); break;
    default : break;
  }
}

bool isMouseMoving() {
  bool mouseMoving=false;
  for(uint8_t i=0;i<keyb.getSize();i++) {
    KeyRaw code =  functionOverride(keyb.getVal(i));
    mouseMoving = mouseMoving || code.isMouseMove();
  }
  return mouseMoving;
}

void keepPressingFunctionKeys(long kMillis) {
  static long mouseMoveStartMills=kMillis;

  // currently this function handles mouse move only
  bool mouseMoving=isMouseMoving();
  uint8_t move=0;
  if(!mouseMoving) mouseMoveStartMills=kMillis;
  if(mouseMoving) move=calcMouseMove(kMillis,mouseMoveStartMills,config.wheel);
  for(uint8_t i=0;i<keyb.getSize();i++) {
    KeyRaw code=functionOverride(keyb.getVal(i));
    if(mouseMoving && code.isMouseMove()) keepMouseMoving(code,move);
  }
}

bool processPress(long kMillis) {
  bool fnPressed=processPressList(kMillis,pressFunction);
  bool usbPressed=processPressList(kMillis,pressNormal);
  keepPressingFunctionKeys(kMillis);

  if(usbPressed) BootKeyboard.send(); // this is actual effect!
  return fnPressed || usbPressed;
}

bool releaseFunction(KeyPos pos) {
  bool released=false;
  KeyRaw code = functionOverride(pos);
  if(code.isFunction() && !keyDebouncer[pos.index()].isReleaseConfirmed()) {    
    //Serial.println(code.function);
    switch(code.function) {
      case FN_SWITCH : config.layer=0; break;
      case FN_MOUSE : 
        config.mouse=false; 
        BootMouse.release(MOUSE_LEFT); // release buttons just in case they were pressed when mouse button was released
        BootMouse.release(MOUSE_RIGHT);
        break;
      case FN_MOUSE_BTN_LEFT : BootMouse.release(MOUSE_LEFT); break;
      case FN_MOUSE_BTN_RIGHT : BootMouse.release(MOUSE_RIGHT); break;
      case FN_MOUSE_WHEEL : config.wheel=false; break;
      default : break;
    }
    keyDebouncer[pos.index()].confirmRelease();
    released=true;
  }
  return released;
}

bool releaseNormal(KeyPos pos) {
  bool released=false;
  if(pos.code(config.layer).isStandard()) {
    //Serial.println(String(index)+" - "+String(functionIndex));
    //if(index==functionIndex) Serial.println(String(keyDebouncer[index].isPressed()));
    KeyRaw code=pos.code(config.layer);
    if(code.mod!=KEY_RESERVED) BootKeyboard.remove(code.mod);
    KeyboardKeycode actualCode=keycodeOverride(pos);
    if(actualCode!=KEY_RESERVED) BootKeyboard.remove(actualCode);
    released=code.standardNonEmpty();
    //Serial.println("pressed " + String(code.key) + " (" + String(code.mod)+")");        
  }
  return released;
}

bool processReleaseOne(uint8_t keyIndex, long kMillis, bool (*process)(KeyPos pos)) {
  bool released=false;
  KeyPos pos=keybPrev.getVal(keyIndex);
  if(keyb.notExists(pos) && keyDebouncer[pos.index()].shouldRelease(kMillis)) released|=(*process)(pos);
  return released;
}

bool processReleaseList(long kMillis, bool (*process)(KeyPos pos)) {
  bool released = false;
  for(uint8_t i=0;i<keybPrev.getSize();i++) released|=processReleaseOne(i,kMillis,process);
  return released;
}

bool processRelease(long kMillis) {
  bool fnReleased=processReleaseList(kMillis,releaseFunction);
  bool usbReleased=processReleaseList(kMillis,releaseNormal);

  if(usbReleased) BootKeyboard.send(); // this is actual effect!
  return fnReleased || usbReleased;
}

void clearIfEmpty(long kMillis) {
  static long lastReleaseMillis=0;
  //NOTE: isEmpty is true only if all keys (incl FN, Mouse, Wheel) are released
  if((keyb.isEmpty() || (keyb.getSize()==1 && keyb.getVal(0).isMouse())) && kMillis-lastReleaseMillis>RELEASE_MILLIS) {
    //Serial.println("empty" +String(kMillis));
    BootKeyboard.removeAll();
    BootKeyboard.send(); // this is actual effect!
    lastReleaseMillis=kMillis;
    config.layer=0;
    for(uint8_t i=0;i<SIZE;i++) keyDebouncer[i].init();
  }
}

void writeColumns(uint8_t col) {
  for(uint8_t i=0;i<COL_PINS;i++) digitalWrite(COLpins[i],col & (1 << i)); // 0 for selected column, 1 otherwise
}

void copyKeyState() {
  keybPrev.empty();
  for(uint8_t i=0;i<keyb.getSize();i++) keybPrev.insertVal(keyb.getVal(i));
}

float mouseSpeedRatio(long pressDurationMillis,bool slow) {
  float ratio=0.0;
  if(pressDurationMillis<100) ratio=0.0;
  else if (pressDurationMillis<500) ratio=0.1;
  else if (pressDurationMillis<1000) ratio=0.1+0.9*(pressDurationMillis-500.0)/(1000.0-500.0);
  else ratio=1.00;
  if(slow) ratio=ratio/15.0;
  return ratio; 
}

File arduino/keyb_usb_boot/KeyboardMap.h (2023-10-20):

#include "HID-Project.h"

#define ROWS 5 // IN
#define COLS 15 // OUT
#define COL_PINS 4 // OUT - using 4 to 16 decoder
#define SIZE ROWS*COLS // size of the matrix
#define LAYERS 2

const uint8_t COLpins[COL_PINS] = {4,5,6,8}; // output (4 to 16 decoder)
const uint8_t ROWpins[ROWS] = {22,21,20,19,18}; // input
const uint8_t COLmap[COLS] = {10,9,8,7,6,5,4,3,2,1,0,11,12,13,14}; // mapping of physical pins to logical columns

enum KeyFunction : uint8_t {
  FN_NORM = 0,
  FN_SWITCH = 1,
  FN_MOUSE_BTN_LEFT = 2,
  FN_MOUSE_BTN_RIGHT = 3,
  FN_MOUSE_WHEEL = 4,
  FN_MOUSE_UP = 5, 
  FN_MOUSE_DOWN = 6, 
  FN_MOUSE_LEFT = 7, 
  FN_MOUSE_RIGHT = 8, 
  FN_MOUSE = 9
};

struct KeyInfo {
  KeyboardKeycode mod; 
  KeyboardKeycode key;
};

struct KeyRaw {
  KeyboardKeycode mod; 
  KeyboardKeycode key;
  KeyFunction function;

  bool isStandard() { return function==FN_NORM;}
  bool isFunction() { return !isStandard();}
  bool standardNonEmpty() { return isStandard() && (mod!=KEY_RESERVED || key!=KEY_RESERVED); }
  bool isMouseMove() { return function==FN_MOUSE_UP || function==FN_MOUSE_DOWN || function==FN_MOUSE_LEFT || function==FN_MOUSE_RIGHT;}
};

struct KeyConfig {
  uint8_t layer; 
  bool mouse;
  bool wheel;
};


const KeyInfo keyMap[ROWS*COLS*LAYERS] {
  {KEY_RESERVED,KEY_ESC},{KEY_RESERVED,KEY_1},{KEY_RESERVED,KEY_2},{KEY_RESERVED,KEY_3},{KEY_RESERVED,KEY_4},
    {KEY_RESERVED,KEY_5},{KEY_RESERVED,KEY_6},{KEY_RESERVED,KEY_7},{KEY_RESERVED,KEY_8},{KEY_RESERVED,KEY_9},
      {KEY_RESERVED,KEY_0},{KEY_RESERVED,KEY_MINUS},{KEY_RESERVED,KEY_EQUAL},{KEY_RESERVED,KEY_DELETE},{KEY_RESERVED,KEY_BACKSPACE},
  {KEY_RESERVED,KEY_TAB},{KEY_RESERVED,KEY_Q},{KEY_RESERVED,KEY_W},{KEY_RESERVED,KEY_E},{KEY_RESERVED,KEY_R},
    {KEY_RESERVED,KEY_T},{KEY_RESERVED,KEY_Y},{KEY_RESERVED,KEY_U},{KEY_RESERVED,KEY_I},{KEY_RESERVED,KEY_O},
      {KEY_RESERVED,KEY_P},{KEY_RESERVED,KEY_LEFT_BRACE},{KEY_RESERVED,KEY_RIGHT_BRACE},{KEY_RESERVED,KEY_BACKSLASH},{KEY_RESERVED,KEY_HOME},
  {KEY_RESERVED,KEY_CAPS_LOCK},{KEY_RESERVED,KEY_A},{KEY_RESERVED,KEY_S},{KEY_RESERVED,KEY_D},{KEY_RESERVED,KEY_F},
    {KEY_RESERVED,KEY_G},{KEY_RESERVED,KEY_H},{KEY_RESERVED,KEY_J},{KEY_RESERVED,KEY_K},{KEY_RESERVED,KEY_L},
      {KEY_RESERVED,KEY_SEMICOLON},{KEY_RESERVED,KEY_QUOTE},{KEY_RESERVED,KEY_ENTER},{KEY_RESERVED,KEY_END},{KEY_RESERVED,KEY_RESERVED},
  {KEY_LEFT_SHIFT,KEY_RESERVED},{KEY_RESERVED,KEY_RESERVED},{KEY_RESERVED,KEY_Z},{KEY_RESERVED,KEY_X},{KEY_RESERVED,KEY_C},
    {KEY_RESERVED,KEY_V},{KEY_RESERVED,KEY_B},{KEY_RESERVED,KEY_N},{KEY_RESERVED,KEY_M},{KEY_RESERVED,KEY_COMMA},
      {KEY_RESERVED,KEY_PERIOD},{KEY_RESERVED,KEY_SLASH},{KEY_RIGHT_SHIFT,KEY_RESERVED},{KEY_RESERVED,KEY_UP_ARROW},{KEY_RESERVED,KEY_RESERVED},
  {KEY_RESERVED,KEY_RESERVED},{KEY_LEFT_CTRL,KEY_RESERVED},{KEY_LEFT_WINDOWS,KEY_RESERVED},{KEY_LEFT_ALT,KEY_RESERVED},{KEY_RESERVED,KEY_SPACE},
    {KEY_RESERVED,KEY_SPACE},{KEY_RESERVED,KEY_SPACE},{KEY_RESERVED,KEY_SPACE},{KEY_RESERVED,KEY_SPACE},{KEY_RESERVED,KEY_SPACE},
      {KEY_RIGHT_ALT,KEY_RESERVED},{KEY_RIGHT_CTRL,KEY_RESERVED},{KEY_RESERVED,KEY_LEFT_ARROW},{KEY_RESERVED,KEY_DOWN_ARROW},{KEY_RESERVED,KEY_RIGHT_ARROW},
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

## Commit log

2023-10-12 copy local files
    [71a48d4e9e6aa89030e797956ad6ba44319560fd_bottom.dxf, 71a48d4e9e6aa89030e797956ad6ba44319560fd_closed.dxf, 71a48d4e9e6aa89030e797956ad6ba44319560fd_open.dxf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]
2023-10-12 press and hold FN to switch from layer 0 to 1
2023-10-12 add separate mouse button (next to left Shiht)
2023-10-12 handle mouse button, correct wheel direction
    [KeyboardMap.h, keyb_usb_boot.ino]
2023-10-12 correct mouse move speed
    [KeyboardMap.h, keyb_usb_boot.ino]
